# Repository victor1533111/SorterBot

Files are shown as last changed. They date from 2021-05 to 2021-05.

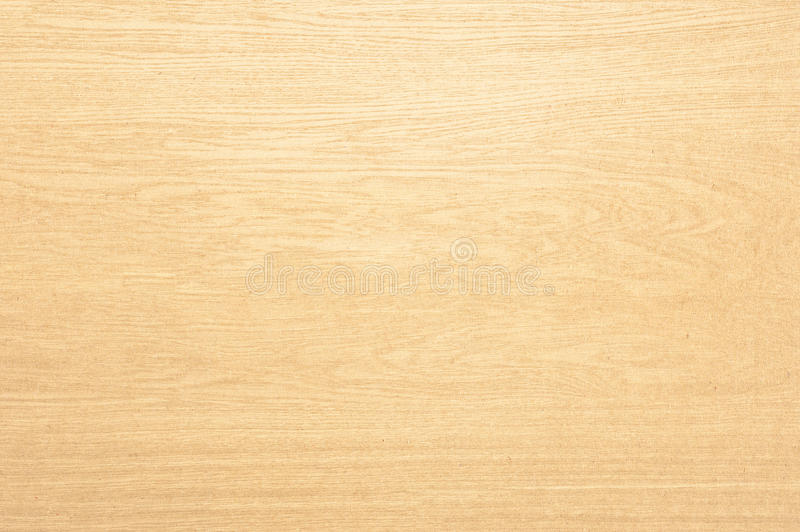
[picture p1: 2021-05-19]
COMPONENTES/TEXTURAS/Colores/textura-de-madera-de-color-claro-27235359.jpg

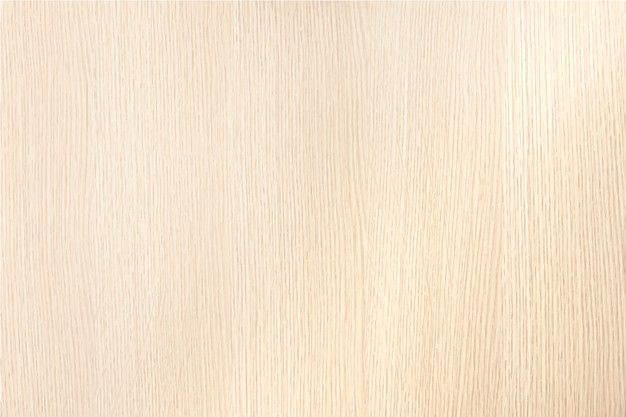
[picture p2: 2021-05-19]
COMPONENTES/TEXTURAS/Colores/wood-texture-background_28943-556.png

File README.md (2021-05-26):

# SorterBot 

<p align="Left">

 </p>

## Table of contents
* [Repository Introduction](#Repository-Introduction)
* [Video](#Video)
* [Code dependencies](#Code-dependencies )
  * [Instalation and uses](#Instalation-and-uses )
* [Project description](#Project-description)
* [Electronic components](#Electronic-components)
* [Hardware Scheme ](#Hardware-Scheme )
* [Extra components and 3D pieces](#Extra-components-and-3D-pieces )
* [Software Architecture ](#Software-Architecture )
* [Simulation Strategy and implementation ](#Simulation-Strategy-and-implementation )
* [Tests](#Tests)
  * [Title sorting test](#Title-sorting-test)
  * [Data sorting test](#Data-sorting-test)
  * [Sheet detection test](#Sheet-detection-test)
  * [Sheet Orientation test](#Sheet-Orientation-test)
* [Contributions](#Contributions)
* [Authors](#Authors )
* [References](#References)

## Repository Introduction
This repository contains all the software modules, all the 3d files and the scenarios that make up our robotics project.
The available code and the 3d designs have been designed by the members of the RPL 2020-2021 group of computer engineering of the UAB formed by Cristian Gutiérrez, Carlos Peña and Víctor Batista and directed by the tutors Luis Vilariano and Carlos García.

## Video

Video (https://www.youtube.com/watch?v=GDZ8xmWGUts)

## Code dependencies

-Tesseract OCR (pipenv , Pillow , pythonRLSA )

-OpenCV

-Jupyter

-CoppeliaSim

-Fuzzywuzzy

   * ## Instalation and uses
   The first thing to do is to install tesseract, to do this you have to access the code folder and run the tesseract application, once run just select the next option until the    last tab where you have to select finish. Important not to change the installation path since it will be the one used in the execution of the code.
   With respect to the rest of dependencies it is necessary to accede to the program and to change the second block of code of markdown to code and to execute it.
   Once the requirements have been installed, perform the following steps:
   1. Open the coppeliasim program with the scenario you wish to run. 
   
   2. Access the jupyter notebook and run all the blocks.
  
   3. A box with two buttons will appear, click the button depending on the scenario you have chosen.

## Project description
SorterBot is a pick and place robot that through the use of a hydraulic pump and a suction cup is able to perform two functionalities which are to classify subject notes by their title and to sort them by the relevant date that appears in those notes.
To perform the first functionality SorterBot implements computer vision by means of a camera that allows it to visualize the content of the notes. From the content it analyzes, it saves the information of the titles in order to classify them according to the subject to which they correspond. Also note that in case there are sheets that do not contain information on subjects or there are more subjects than available spaces, it classifies them in a separate set.
The second functionality, as we have already mentioned, allows us to organize the notes of a subject by dates. For this SorterBot uses computer vision that allows it to visualize the content of the notes from which it extracts the date that appears at the top of the sheet. Once the date is obtained, it uses the Hanoi algorithm with which it groups the sheets in different blocks depending on whether they correspond to an older or more current date in order to place them in an orderly fashion.
To highlight as contributions that It is a project that has a direct and wide application since it is automating a very frequent problem, the sorting of physical documents and their classification into different categories, thus allowing its use in any work or leisure environment and that Our robot differs from other pick & place robots[1] because it can apply different strategies and algorithms to classify and group documents. It should be noted that these strategies are based on the treatment of images of documents and on obtaining their information, thus allowing us to use it in any case where there is text, since it does not focus on the form but on the content.

## Electronic components
■ 1x Arduino

■ 1x Vacuum pump 

■ 1x Suction cup 

■ 1x Raspberry pi

■ 1x Raspberry pi camera 

■ 1x Power supply unit (8v) 

■ 3x Servomotor (1 x MG995 ->15kg, 2x MG90S -> 2,2kg) -> require de 4.8 a 7.3 v

■ 1x Infrared proximity sensor 

■ 1x Robot Skeleton

## Hardware Scheme 

<p align="center">
 
 </p>
 
## Extra components and 3D pieces
■ 2 Buttons

■ Body

■ Rotational arm

■ Proximity sensor holder

■ Prismatic arm

■ Flexible suction tube

■ Camera support

■ Suction tube storage and prismatic overlay (Vacuum zone)

■ Base arm support

■ 6 bars

■ Nuts and bolts

■ Servomotor Box

<p align="center">
 
 </p>

The main part of SorterBot is the body which apart from being an important part as far as the weight distribution of the structure is concerned, is the part where the vacuum pump and the robot's computers are kept, which in this case are the arduino and the raspberry pi.
In the body itself we find two buttons placed on its square base that allow us to select between the sorting algorithm (red button) and the organization (green button).
Next to this body we find a rotational arm connected by 4 bars that allows us to increase the mobilization of the body in the axis of the and, in addition to perform a 360 degree angle by means of the servomotor that is incorporated in the servomotor box located on top of the arm.
On top of this arm we find the piece that allows us to partially cover the prismatic arm as it moves along the z-axis, in addition to being the receiver of the flexible suction tube that is connected to the vacuum pump that goes from the base to the storage and generates the suction force of the suction cup [2]. It should be noted that this part allows us to create a vacuum zone.
Finally we find the camera support attached to the rotational arm and the proximity sensor support attached to the prismatic arm.
These two supports allow us in the first case to hold the camera of the raspberry pi perpendicular to the points, as well as to protect it and in the second case to place the sensor near the suction cup to calculate the distance to the object.

## Software Architecture
<p align="center">
 
 </p>
  
## Simulation Strategy and implementation

To simulate the project the first thing we do is to define the 3D design of the robot
using the TinkerCad application.
Once the design is done we export it in MTL format to be able to import it into the
Coppelia Sim platform keeping its colors.
In this platform we add the pertinent links that correspond to the servomotors of
our robot and we add a sensor to be able to visualize objects and another sensor to
detect the proximity[3] to these.
Once the robot is assembled we have defined several scenarios both for the
realization of the algorithms and for testing.
The first of them is a scenario in which we have defined a work table, a set of 6 file
cabinets that are at the following angles 45,90,-90,120,-120,150,-150,180, and a series
of sheets containing information of various subjects that are oriented at the zero
position of the robot.

<p align="Center">


 </p>

These angles have been chosen because of the size of the sheets, otherwise the binders would collide.
Also note that the angle -45 is reserved for the orientation of the leaves, otherwise it could be the case that there are two leaves in which the top one is well oriented and the bottom one is badly oriented and consequently an erroneous calculation would be made as shown in the following image:

<p align="Center">


 </p>
In this scenario the robot is responsible for performing the classification algorithm for which it takes each sheet independently by using the proximity sensor that allows us to stop the arm before colliding with the sheets,  and takes them to the orientation angle to see whether or not it is necessary to rotate them. Once the sheet is well oriented, the extraction of the text and identification of the title is carried out and then, by means of a strategy of percentage [4] of appearance and similarity of words, it is placed in a filing cabinet or other. If there is no subject associated with the sheet, an empty file cabinet will be found to place it, and if there are no file cabinets, it will be placed in the file cabinet located at 180 degrees.
Finally, add that the algorithm ends when it returns to the initial position and observes that there is no sheet of paper.

As a second scenario we have used the same as the previous one but in this case the sheets are already classified in their respective filing cabinets as shown in the following image:
<p align="Center">
 
 </p>
In this scenario we perform the sorting algorithm for which the robot goes to each file cabinet, in a set order, and sorts the sheets by helping the two nearby file cabinets to perform the same.

The algorithm of sorting data is divided into two phases:<br />
1. Read dates: Reads all dates from the stack, storing in an auxiliary angle.<br />
2. Stack Sort Algorithm: Proceeds to sort the sheets, using a maximum of two binders and leaving them in a third one, which corresponds to the binder where the stack to be sorted was.

We make the abstraction of viewing the file cabinets with all their sheets as a stack with elements:
<p align="Center">


 </p>

## Tests
To test the different algorithm modules of the Sorterbot, we have created 3 different scenarios and 4 different test.
 * ## Title sorting test
In this scenario we have a series of sheets with titles with different characteristics such as different sizes, numbers, strange symbols... In this case the scenario that we use is the second scenario and it is used to perform the title test in which the correct extraction of these titles will be checked with the corresponding elimination of elements that do not provide information. To evaluate the robustness of this title, the comparison of similarity with the correct titles is applied to make the sum of the percentages of similarity error.

It should be noted that the results obtained for this test have a 1.5 percent error rate.
 * ## Data sorting test  
 
The test itself consists of storing the result of the sorting in a list along the total sorting of all file cabinets.
Finally it is compared with the expected result to see if the sorting has been done correctly.
This test is useful to detect errors in the camera, the sorting algorithm and the general and functional operation of the MVP.
As a result, we have obtained the correct identification and conversion of all the dates

 * ## Sheet detection test
This test is performed in scenario 2 aswell.
The purpose of this test is to check that when there is an empty tray, the robot ignores this tray and continues with the sorting.
As results we have not obtained any problem in this test and its correct resolution has been performed.
 * ## Sheet Orientation test
In this case the test belongs to the third scenario which consist in only one filing cabinet in position -90 and a pile of misguided sheets as shown in the following image:
<p align="Center">

</p>
In this scenario we test the orientation algorithm for which the robot picks a sheet from the origin pile, then it moves it to orientation -45 where aren’t any noises, there the camera takes a photo of the sheet. Finaly we use computer vision techniques to take the longest line in the image corresponding to the sheet’s heigh, we detect angle of that line and then we proceed to correctly orientate it and place it in the filing cabinet.

The test consists in calculate the total error, the sum of the absolute error of all the sheets after being properly orientated.



As we can see, in a sample of 20 sheets the sum of existing errors was below 1 degree.

## Contributions
This is open source, any contribution is welcome. 

## Authors
Víctor Batista Medeiros - <a href="https://github.com/victor1533111">Github</a>

Carlos Peña de Pedro - <a href="https://github.com/CarlosPenaDePedro">Github</a>

Cristian Gutiérrez Gómez - <a href="https://github.com/cristiangutierrz">Github</a>

## References

[1] FANUC America Corporation (16 mar 2018). High Speed SCARA Robot for Pick & Place [YouTube]. https://youtu.be/-m1oKuFkSTE

[2] How to Control Vacuum Pump Air Pump Suction for Robotic Arm (January 30, 2021). [Web Page]. https://create.arduino.cc/projecthub/ronfrtek/how-to-control-vacuum-pump-air-pump-suction-for-robotic-arm-5de318

[3] Armesto, L. (12 feb 2020). Cómo Usar los Sensores de Proximidad para Permanecer entre Paredes [YouTube]. https://youtu.be/j4dMnAPZu70

[4] Gitau, C. (2020, 11 enero). Fuzzy String Matching - Towards Data Science. Medium. https://towardsdatascience.com/fuzzy-string-matching-in-python

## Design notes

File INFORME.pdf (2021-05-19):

RPL - Computer Engineering. UAB (Barcelona) 2020-2021

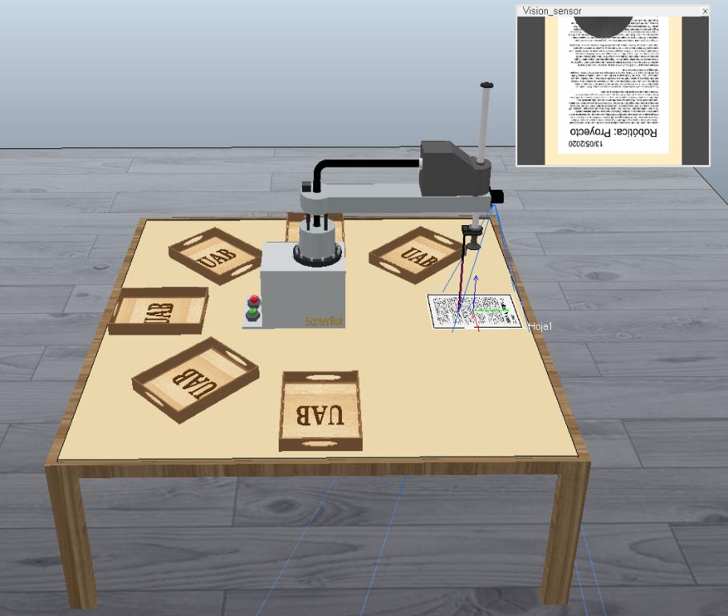
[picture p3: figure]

# SorterBot

Hydraulic arm that classifies notes according to the subject by computer vision and allows them to be sorted by date.

PROJECT SPRINT #4.
DATE: 18th May 2021
Víctor Batista Medeiros-1533111 Cristian Gutiérrez Gómez-1532397 Carlos Peña de Pedro-1532529

SorterBot

# Table of Contents

Project description | 1
Electronic components | 2
Schemes | 3
Amazing contributions , extra components and 3D pieces | 5
Description and use of pieces | 6
Simulation strategy | 8
Foreseen risks and contingency plan | 14

Sprint #3
Date:28 April 2021
SorterBot | 1

# SorterBot

Hydraulic arm that classifies notes according to the subject by computer vision and allows them to be sorted by date.

Project description

SorterBot is a pick and place robot that through the use of a hydraulic pump and a suction cup is able to perform two functionalities which are to classify subject notes by their title and to sort them by the relevant date that appears in those notes.

To perform the first functionality SorterBot implements computer vision by means of a camera that allows it to visualize the content of the notes. From the content it analyzes, it saves the information of the titles in order to classify them according to the subject to which they correspond. Also note that in case there are sheets that do not contain information on subjects or there are more subjects than available spaces, it classifies them in a separate set.

The second functionality, as we have already mentioned, allows us to organize the notes of a subject by dates. For this SorterBot uses computer vision that allows it to visualize the content of the notes from which it extracts the date that appears at the top of the sheet. Once the date is obtained, it uses the Hanoi algorithm with which it groups the sheets in different blocks depending on whether they correspond to an older or more current date in order to place them in an orderly fashion.

SorterBot | 2

Electronic components

■ | 1x Arduino
■ | 1x Vacuum pump
■ | 1x Suction cup
■ | 1x Raspberry pi
■ | 1x Raspberry pi camera
■ | 1x Power supply unit (8v)
■ | 3x Servomotor (1 x MG995 ->15kg, 2x MG90S -> 2,2kg) -> require de 4.8 a 7.3 v

■ 1x Infrared proximity sensor

■ 1x Robot Skeleton

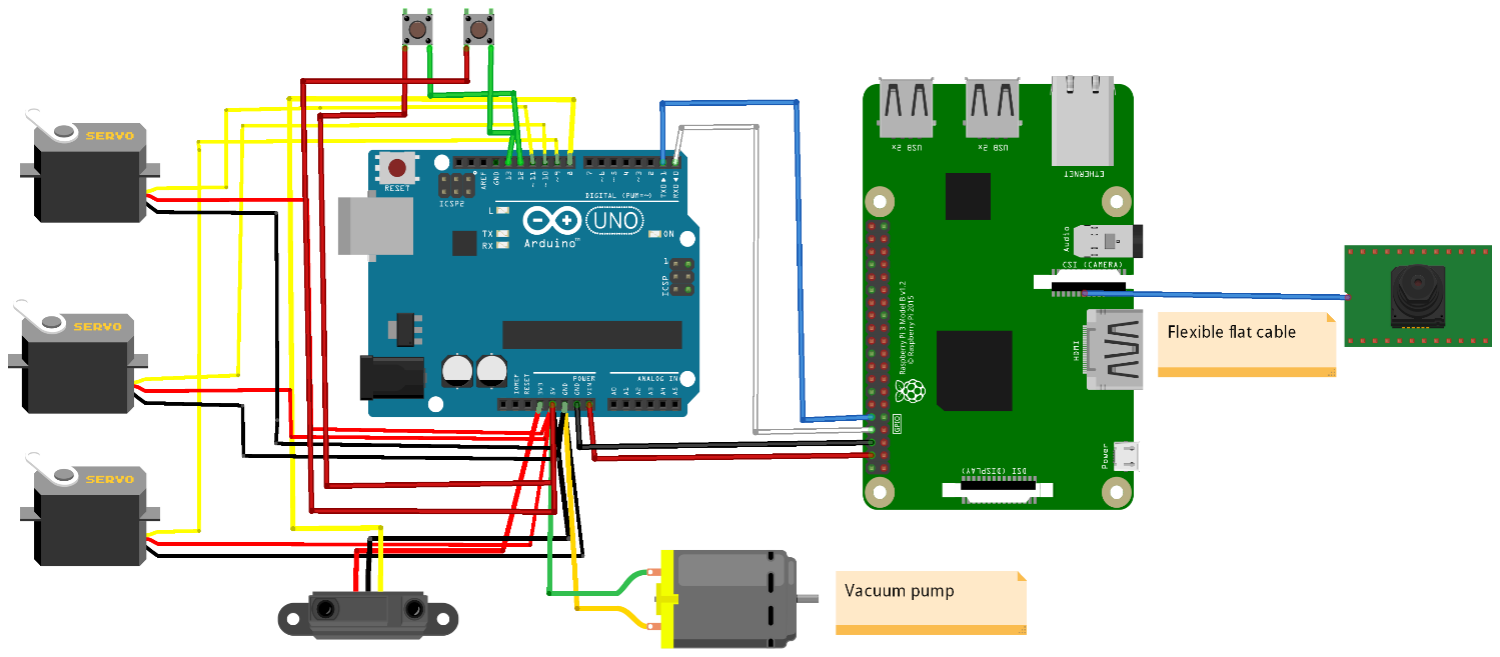
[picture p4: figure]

SorterBot | 3

Hardware Scheme

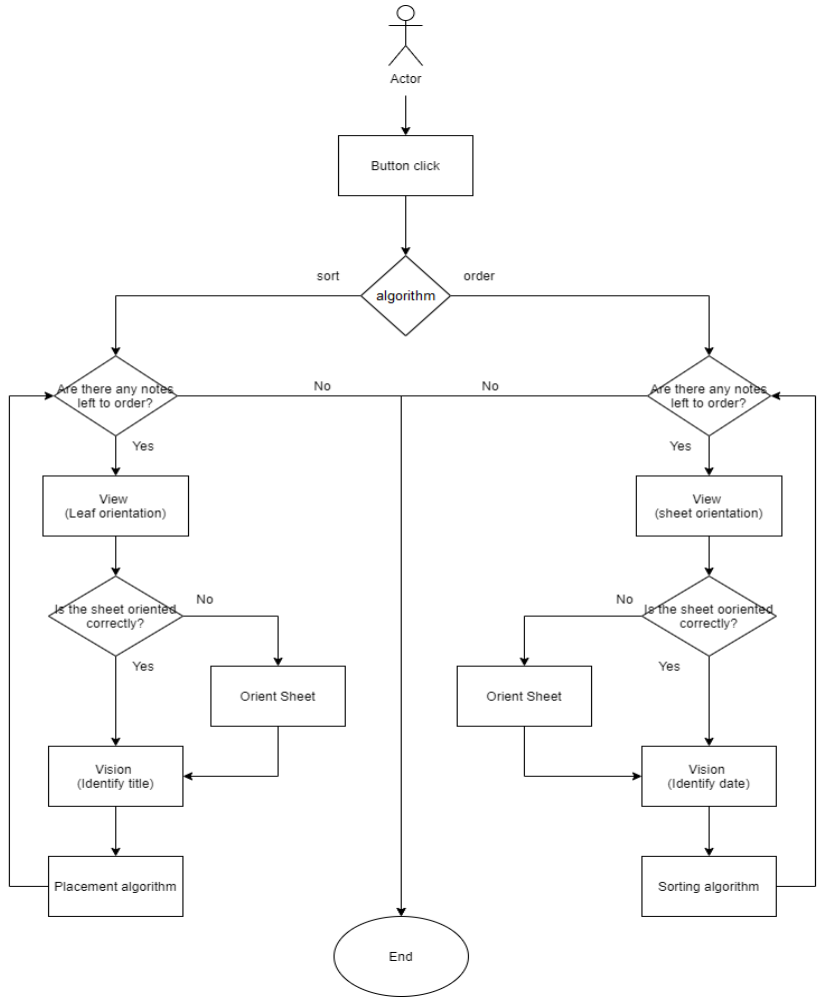
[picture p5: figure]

SorterBot | 4

Software Architecture

SorterBot | 5

Amazing contributions

■ It is a project that has a direct and wide application since it is automating a very frequent problem, the sorting of physical documents and their classification into different categories, thus allowing its use in any work or leisure environment.

■ Our robot differs from other pick & place robots[1] because it can apply different strategies and algorithms to classify and group documents. It should be noted that these strategies are based on the treatment of images of documents and on obtaining their information, thus allowing us to use it in any case where there is text, since it does not focus on the form but on the content.

Extra components and 3D pieces

■ 2 Buttons

■ Body

■ Rotational arm

■ Proximity sensor holder

■ Prismatic arm

■ Flexible suction tube

■ Camera support

■ Suction tube storage and prismatic overlay (Vacuum zone)

■ Base arm support

■ 6 bars

■ Nuts and bolts

■ Servomotor Box

SorterBot | 6

Description and use of pieces

The main part of SorterBot is the body which apart from being an important part as far as the weight distribution of the structure is concerned, is the part where the vacuum pump and the robot's computers are kept, which in this case are the arduino and the raspberry pi.

In the body itself we find two buttons placed on its square base that allow us to select between the sorting algorithm (red button) and the organization (green button).

Next to this body we find a rotational arm connected by 4 bars that allows us to increase the mobilization of the body in the axis of the and, in addition to perform a 360 degree angle by means of the servomotor that is incorporated in the servomotor box located on top of the arm.

On top of this arm we find the piece that allows us to partially cover the prismatic arm as it moves along the z-axis, in addition to being the receiver of the flexible suction tube that is connected to the vacuum pump that goes from the base to the storage and generates the suction force of the suction cup [2]. It should be noted that this part allows us to create a vacuum zone.

Finally we find the camera support attached to the rotational arm and the proximity sensor support attached to the prismatic arm.

These two supports allow us in the first case to hold the camera of the raspberry pi perpendicular to the points, as well as to protect it and in the second case to place the sensor near the suction cup to calculate the distance to the object.

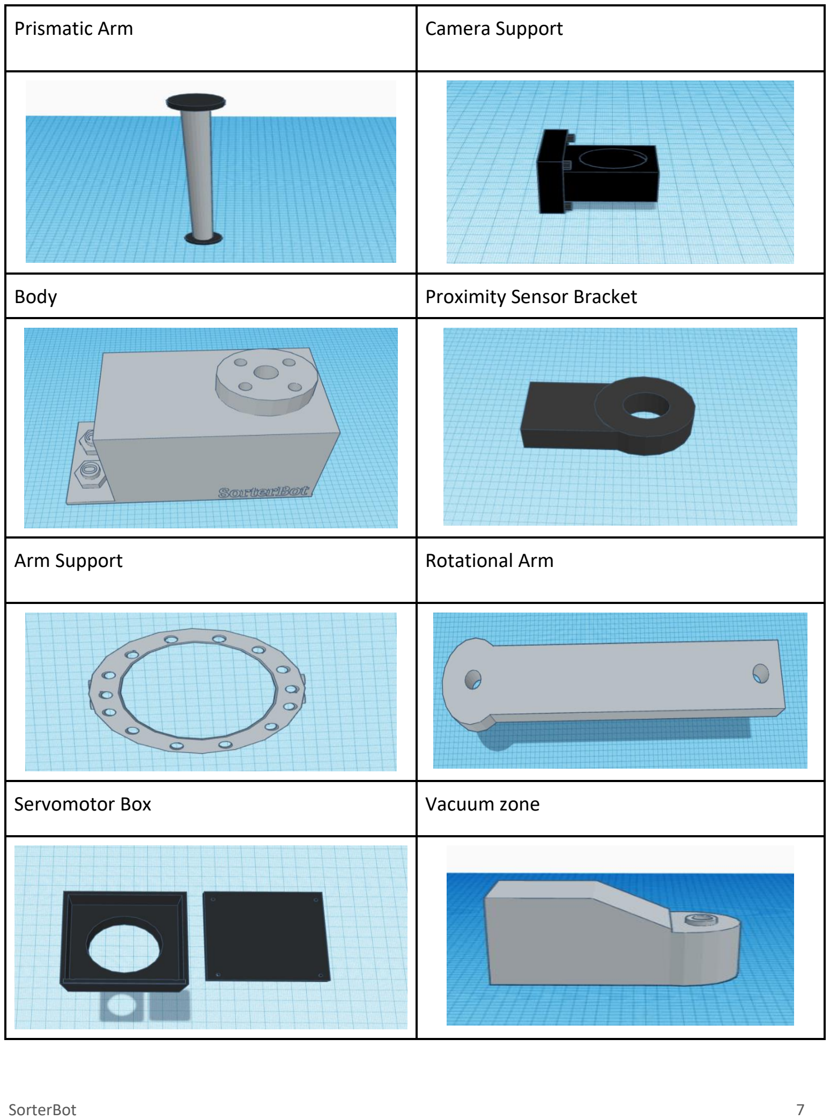
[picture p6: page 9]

SorterBot | 7
Prismatic Arm | Camera Support
Body | Proximity Sensor Bracket
Arm Support | Rotational Arm
Servomotor Box | Vacuum zone

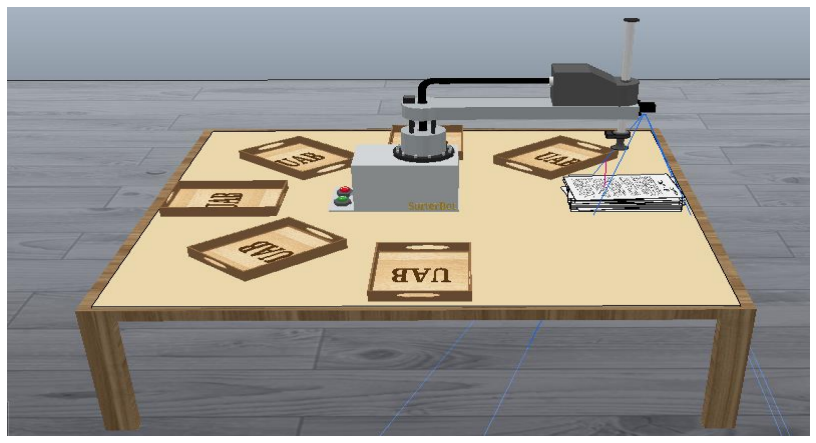
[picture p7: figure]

SorterBot | 8

Simulation Strategy

To simulate the project the first thing we do is to define the 3D design of the robot using the TinkerCad application.
Once the design is done we export it in MTL format to be able to import it into the Coppelia Sim platform keeping its colors.
In this platform we add the pertinent links that correspond to the servomotors of our robot and we add a sensor to be able to visualize objects and another sensor to detect the proximity[3] to these.
Once the robot is assembled we have defined several scenarios both for the realization of the algorithms and for testing.
The first of them is a scenario in which we have defined a work table, a set of 6 file cabinets that are at the following angles 45,90,-90,120,-120,150,-150,180, and a series of sheets containing information of various subjects that are oriented at the zero position of the robot

Image 1: Clasification scenario.

These angles have been chosen because of the size of the sheets, otherwise the binders would collide.

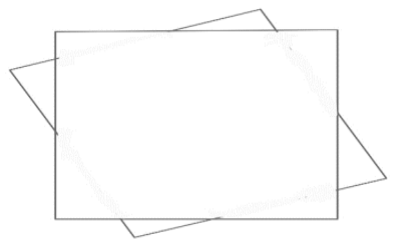
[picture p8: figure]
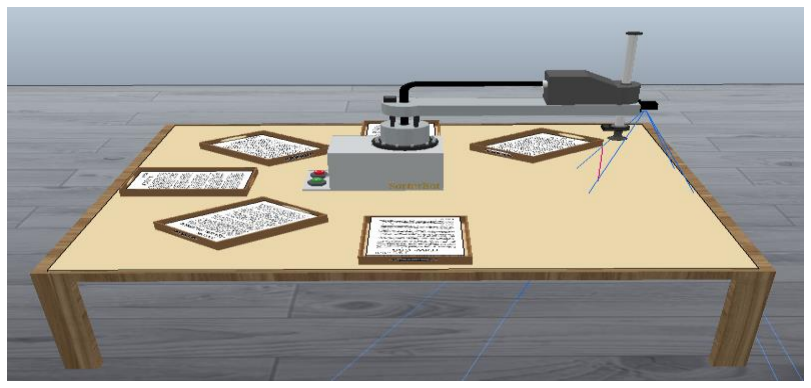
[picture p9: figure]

SorterBot | 9

Also note that the angle -45 is reserved for the orientation of the leaves, otherwise it could be the case that there are two leaves in which the top one is well oriented and the bottom one is badly oriented and consequently an erroneous calculation would be made as shown in the following image:

Image 2: Set of leaves with the lower leaf oriented wrongly.

In this scenario the robot is responsible for performing the classification algorithm for which it takes each sheet independently by using the proximity sensor that allows us to stop the arm before colliding with the sheets, and takes them to the orientation angle to see whether or not it is necessary to rotate them. Once the sheet is well oriented, the extraction of the text and identification of the title is carried out and then, by means of a strategy of percentage [4] of appearance and similarity of words, it is placed in a filing cabinet or other. If there is no subject associated with the sheet, an empty file cabinet will be found to place it, and if there are no file cabinets, it will be placed in the file cabinet located at 180 degrees.

As a second scenario we have used the same as the previous one but in this case the
sheets are already classified in their respective filing cabinets as shown in the following image:

Image 3: Management scenario.

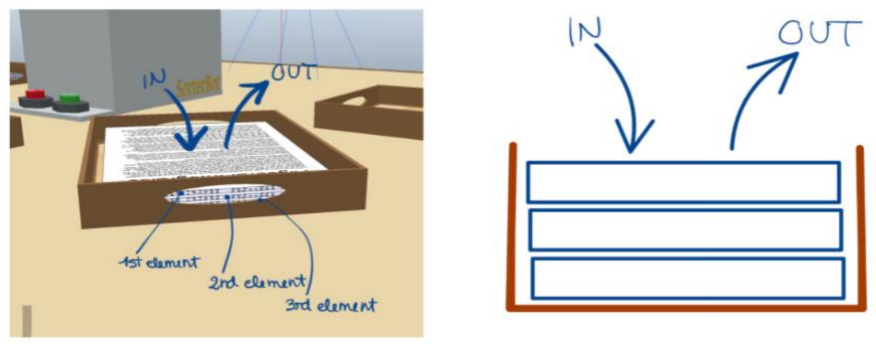
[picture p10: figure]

SorterBot | 10

In this scenario we perform the sorting algorithm for which the robot goes to each file cabinet, in a set order, and sorts the sheets by helping the two nearby file cabinets to perform the same.

It is divided into two phases:

1. Read dates: Reads all dates from the stack, storing in an auxiliary angle.
2. Stack Sort Algorithm: Proceeds to sort the sheets, using a maximum of two binders and leaving them in a third one, which corresponds to the binder where the stack to be sorted was.

We make the abstraction of viewing the file cabinets with all their sheets as a stack with elements:

Image 4: The stack abstraction.

Pseudocode Stack Sort Algorithm

:param unsorted_date_list:
:param a1: angle where the stack is located after reading the dates :param a2: angle at which we will leave the stack sorted
:param atemp: an angle to be used to assist in sorting (will remain empty) returns :param sorted_date_list:

WHILE unsorted_date_list HAS ELEMENTS:
Grab the first paper sheet on the stack (FirstSheet) WHILE sorted_date_list HAS ELEMENTS:
IF date(ordered_date_list[-1]) > date (FirstSheet):
Leave the current sheet to the the axillary “atemp” stack Grab the first paper sheet on the “a2” stack
Leave the current sheet to the the “a1” stack

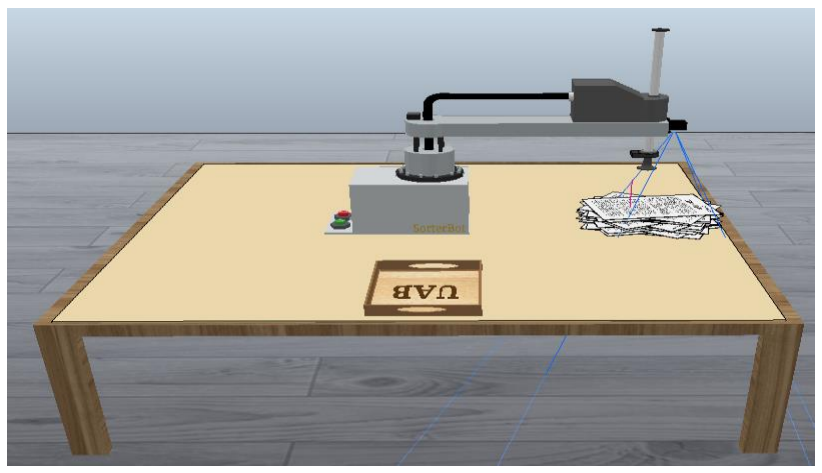
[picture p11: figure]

SorterBot | 11

ELSE:
BREAK
IF sorted_date_list HAS NO ELEMENTS:
Leave the current sheet at the original stack angle “a2” ELSE:
Grab the sheet for the axillary “atemp” stack

Also, in this scenario we perform two tests:

- test_resultat_correcte
It consists of storing the result of the sorting in a list along the total sorting of all file cabinets.
Finally it is compared with the expected result to see if the sorting has been done correctly.
This test is useful to detect errors in the camera, the sorting algorithm and the general and functional operation of the MVP.
- test_arxivador_buit
The purpose of this test is to check that when there is an empty tray, the robot ignores this tray and continues with the sorting.

The fourth scenario consist in only one filing cabinet in position -90 and a pile of misguided sheets as shown in the following image:

Image 5: Management scenario.

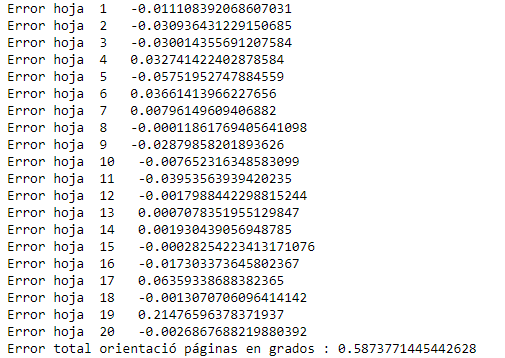
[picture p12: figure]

SorterBot | 12

In this scenario we test the orientation algorithm for which the robot picks a sheet from the origin pile, then it moves it to orientation -45 where aren’t any noises and the camera takes a photo of the sheet. Then we use computer vision techniques to take the longest line in the image corresponding to the sheet’s heigh, we detect angle of that line and then we proceed to correctly orientate it and place it in the filing cabinet.

The test consists in calculate the total error, the sum of the absolute error of all the sheets after being properly orientated.

As we can see in a sample of 20 sheets the sum of existing errors was below 1 degree.

Finally, as the last scenario, we find a scenario in which we have a series of sheets with titles with different characteristics such as different sizes, numbers, strange symbols... In this case this scenario is used to perform the title test in which the correct extraction of these titles will be checked with the corresponding elimination of elements that do not provide information. To evaluate the robustness of this title, the comparison of similarity with the correct titles is applied to make the sum of the percentages of similarity error.

It should be noted that the results obtained for this test have a 1.5 percent error rate.

SorterBot | 13

Foreseen risks and contingency plan

Risk # | Description | Probability (High/Medium/L ow) | Impact (High/Medium/L ow) | Contingency plan
1 | Excessive suction force. | High | High | Correctly adjust the suction valve output.
2 | Inadequate height when depositing foils. | High | High | Use of the motion sensor to correctly adjust the displacement of the prismatic axis
3 | Failures in the title detection system.. | Low | High | Extensive screening and classification of folios by title
4 | Obstruction of the robot by an object not foreseen in the working area. | Low | High | Periodic review of the work area.
5 | Failure to raise the prismatic axis causing the robot to hit the sheets. | Low | High | Automatically raise the prismatic axis to a height greater than the maximum thickness of the piles of foils.

SorterBot | 14
Risk # | Description | Probability (High/Medium/L ow) | Impact (High/Medium/L ow) | Contingency plan
6 | Exceeding the maximum number of subjects to be graded. | Low | Low | Move the excess subject sheets to the default pile.
7 | Folios without content or title to classify. | Low | Low | Move the sheets to the default pile.
8 | Sheets with different date formats. | Medium | Medium | After reading the dates transform them all to the same format.
9 | Undated sheets. | Medium | Low | If a sheet has no date, when using the sort function it will be deposited in a pile in the opposite place to the original one.
10 | Overlapping orientations | High | High | When two sheets are stacked, if the first one is straight and the bottom one is twisted, it will detect the orientation of the second one, so it will be necessary to move each sheet to an empty area before correcting its orientation

SorterBot | 15

References

[1] FANUC America Corporation (16 mar 2018). High Speed SCARA Robot for Pick & Place [YouTube]. https://youtu.be/-m1oKuFkSTE
[2] How to Control Vacuum Pump Air Pump Suction for Robotic Arm (January 30, 2021). [Web Page]. https://create.arduino.cc/projecthub/ronfrtek/how-to-control-vacuum-pump-air-pump-suction-for-robotic-arm-5de318 (https://create.arduino.cc/projecthub/ronfrtek/how-to-control-vacuum-pump-air-pump-suction-for-robotic-arm-5de318)
[3] Armesto, L. (12 feb 2020). Cómo Usar los Sensores de Proximidad para Permanecer entre Paredes [YouTube]. https://youtu.be/j4dMnAPZu70
[4] Gitau, C. (2020, 11 enero). Fuzzy String Matching - Towards Data Science. Medium. https://towardsdatascience.com/fuzzy-string-matching-in-python

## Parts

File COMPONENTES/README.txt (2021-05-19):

En MTL encontraras todos los componentes necesarios para realizar el robot simulable
Mientras que en STL encontraras solo las piezas que se requieren imprimir con una impresora 3D.

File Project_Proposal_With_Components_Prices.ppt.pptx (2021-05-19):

## SORTERBOT

Brazo hidráulico que clasifica apuntes en función de la asignatura mediante visión por computador y que permite ordenarlos por fecha.

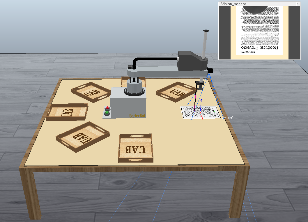
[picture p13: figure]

GROUP_07
Victor Batista Medeiros -1533111
Cristian Gutiérrez Gómez - 1532397
Carlos Peña de Pedro -1532529

Robòtica, llenguatge I planificació – Enginyeria informàtica - uab

## SORTERBOT

Component | Units | Price/unit | Budget
KIT succión (Arduino, bomba vacio, gripper, cables y tubos) | 1 | 33,58 | 33,58
Raspberry pi | 1 | 19,95 | 19,95
RaspBerry pi Camera | 1 | 15,17 | 15,17
Fuente Alimentacion (12v) | 1 | 15,99 | 15,99
Servomotor ( 1 x MG995 ->15kg) | 1 | 6,96 | 6.96
Servomotor (2x MG90S -> 2,2kg) | 2 | 4,95 | 9,9
Sensor infrarrojo de proximidad | 1 | 6.18 | 6.18
Esqueleto Robot | 1 | - | -
TOTAL: | | | 107,73

## Altres enllaços

Projecte en el qual està inspirat

https://youtu.be/eVz7mOJVvQc
https://youtu.be/Tm_Iw5IqTVs

- https://create.arduino.cc/projecthub/ronfrtek/how-to-control-vacuum-pump-air-pump-suction-for-robotic-arm-5de318
- https://youtu.be/efHYZ-Fcfmw
- https://www.youtube.com/watch?v=Gmdvx8TKWOQ&ab_channel=kelongye
- https://es.wikipedia.org/wiki/Torres_de_Han%C3%B3i

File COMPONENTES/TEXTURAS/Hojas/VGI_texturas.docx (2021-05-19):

15/02/2021

VGI : Gabbor

Lorem ipsum dolor sit amet, consectetur adipiscing elit, sed do eiusmod tempor incididunt ut labore et dolore magna aliqua. Aliquet nibh praesent tristique magna sit amet. A diam maecenas sed enim. Orci phasellus egestas tellus rutrum. Porttitor lacus luctus accumsan tortor posuere ac ut consequat. Habitant morbi tristique senectus et. Dui faucibus in ornare quam viverra orci sagittis eu volutpat. Vestibulum sed arcu non odio euismod lacinia. Parturient montes nascetur ridiculus mus mauris. Arcu risus quis varius quam quisque. Elit scelerisque mauris pellentesque pulvinar pellentesque habitant morbi tristique. Sed turpis tincidunt id aliquet risus feugiat in ante metus. Pharetra convallis posuere morbi leo. Mattis nunc sed blandit libero. At augue eget arcu dictum varius duis. Quis auctor elit sed vulputate mi sit amet. Facilisis magna etiam tempor orci eu lobortis elementum nibh tellus. Morbi tristique senectus et netus et. Ornare arcu odio ut sem nulla pharetra diam sit. Pretium quam vulputate dignissim suspendisse in est ante.

Purus ut faucibus pulvinar elementum integer enim neque volutpat. In fermentum et sollicitudin ac orci. Odio tempor orci dapibus ultrices in iaculis nunc sed augue. Vitae suscipit tellus mauris a diam maecenas sed. Leo urna molestie at elementum eu facilisis sed odio. Convallis posuere morbi leo urna molestie at elementum eu. Interdum posuere lorem ipsum dolor sit amet. Turpis egestas sed tempus urna et pharetra pharetra. Mattis aliquam faucibus purus in massa. Faucibus scelerisque eleifend donec pretium. Id aliquet risus feugiat in ante metus dictum at.

Velit sed ullamcorper morbi tincidunt ornare massa. Iaculis eu non diam phasellus vestibulum lorem sed risus. Sit amet dictum sit amet justo donec enim diam. Sagittis nisl rhoncus mattis rhoncus urna neque viverra. Turpis egestas sed tempus urna. Feugiat scelerisque varius morbi enim. Vel turpis nunc eget lorem dolor sed. Aenean vel elit scelerisque mauris pellentesque. Mauris nunc congue nisi vitae. Volutpat consequat mauris nunc congue nisi. Id velit ut tortor pretium viverra suspendisse potenti nullam. Justo eget magna fermentum iaculis eu non diam phasellus. At varius vel pharetra vel turpis nunc eget lorem dolor. Mauris rhoncus aenean vel elit. Potenti nullam ac tortor vitae purus.

Et magnis dis parturient montes nascetur ridiculus. Eget gravida cum sociis natoque penatibus et. Porttitor massa id neque aliquam vestibulum morbi blandit. Aliquet porttitor lacus luctus accumsan. Euismod in pellentesque massa placerat duis ultricies lacus. Dui ut ornare lectus sit amet est. A iaculis at erat pellentesque adipiscing commodo. Molestie ac feugiat sed lectus vestibulum mattis ullamcorper velit. Amet nulla facilisi morbi tempus iaculis. Erat pellentesque adipiscing commodo elit at imperdiet dui accumsan sit. Proin fermentum leo vel orci porta non pulvinar. Sed faucibus turpis in eu mi. Praesent semper feugiat nibh sed pulvinar proin gravida hendrerit.

Nunc sed augue lacus viverra vitae congue. Platea dictumst quisque sagittis purus sit amet volutpat consequat mauris. Sed velit dignissim sodales ut eu sem integer vitae justo. Mi in nulla posuere sollicitudin aliquam ultrices sagittis orci. Est lorem ipsum dolor sit. Dolor sed viverra ipsum nunc aliquet bibendum enim. Vulputate sapien nec sagittis aliquam malesuada bibendum. Amet mauris commodo quis imperdiet massa tincidunt nunc pulvinar. Mi quis hendrerit dolor magna. Ultrices tincidunt arcu non sodales neque sodales ut etiam sit. Sed risus pretium quam vulputate dignissim suspendisse in. Interdum posuere lorem ipsum dolor sit amet. Morbi tristique senectus et netus et malesuada fames ac turpis. Sagittis nisl rhoncus mattis rhoncus urna. Lorem ipsum dolor sit amet

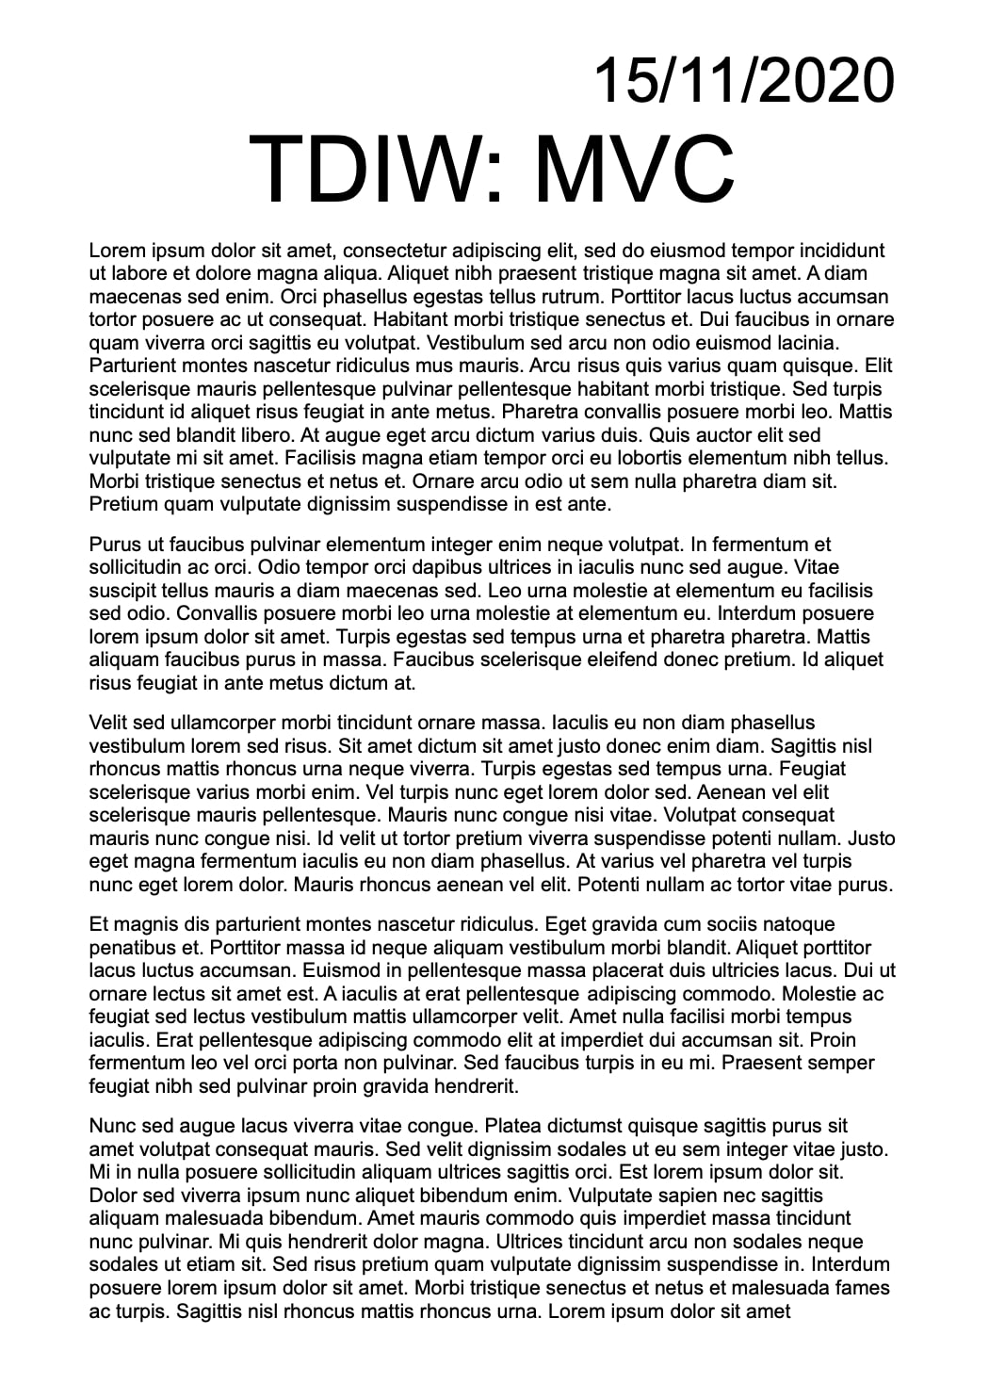
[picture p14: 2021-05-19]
COMPONENTES/TEXTURAS/Hojas/TDIW_MVC.jpg

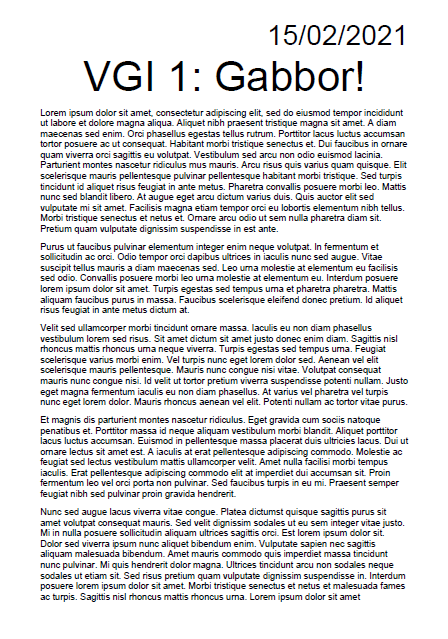
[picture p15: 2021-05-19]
COMPONENTES/TEXTURAS/Hojas/vgiii.PNG

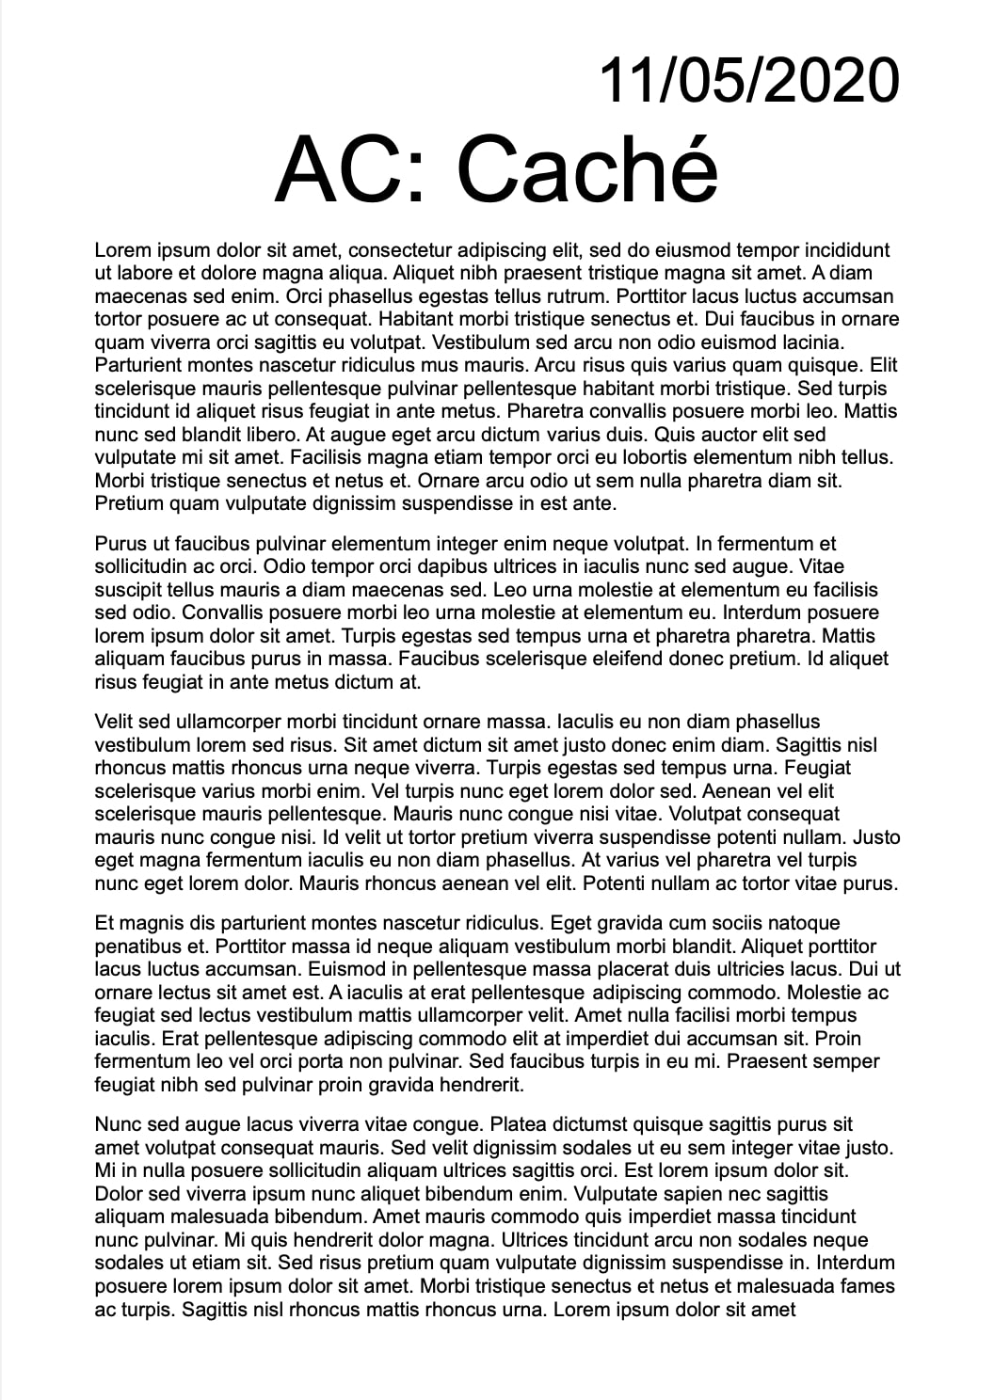
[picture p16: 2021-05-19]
COMPONENTES/TEXTURAS/Hojas/AC_Cache.jpg

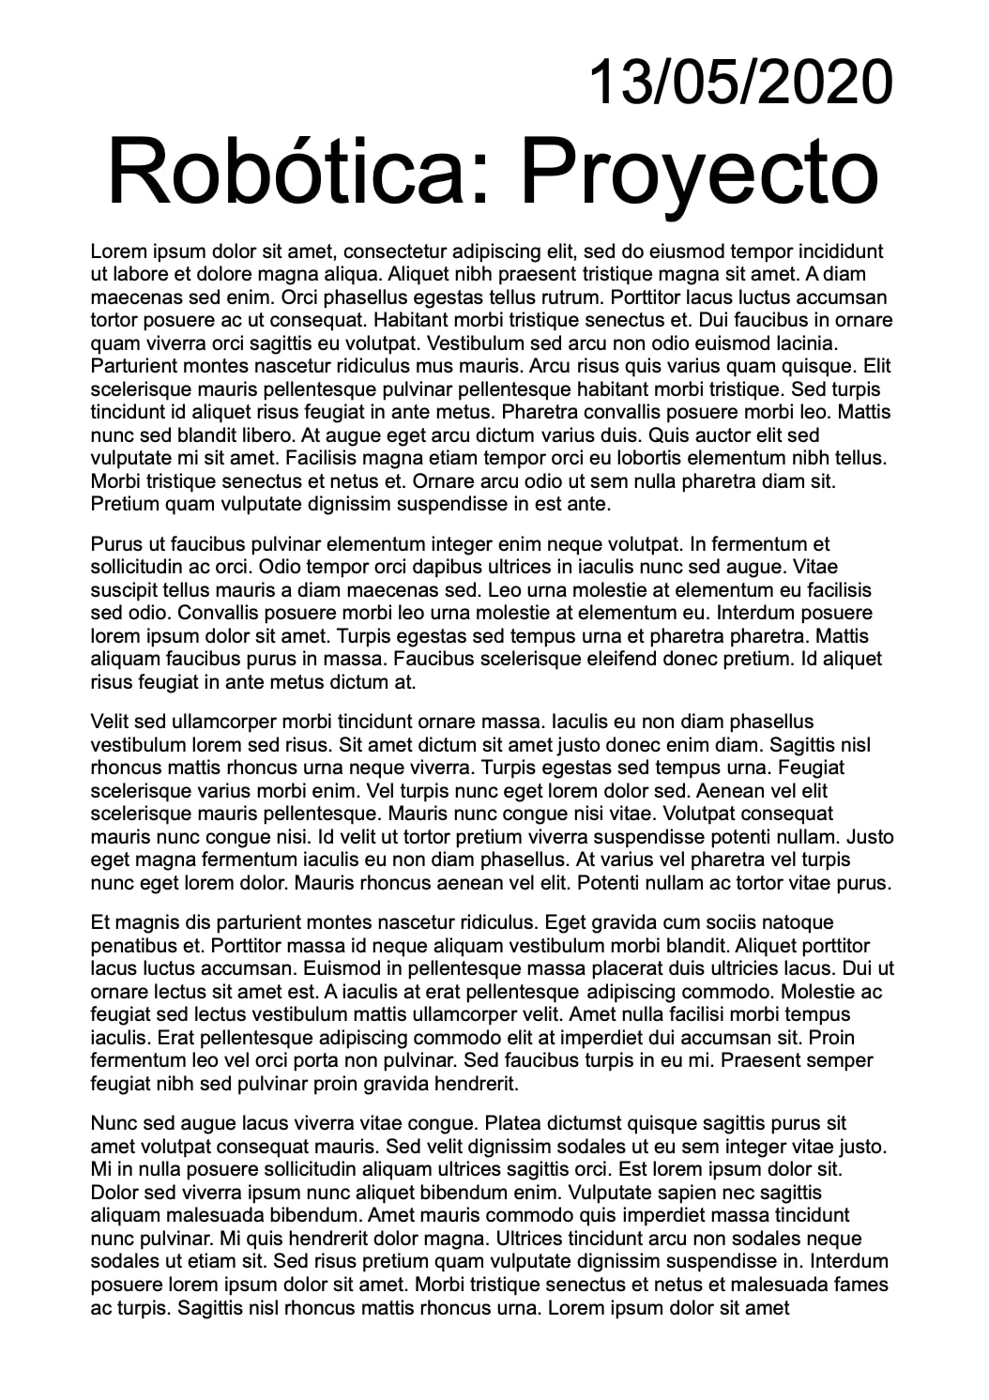
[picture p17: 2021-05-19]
COMPONENTES/TEXTURAS/Hojas/Robotica_Proyecto.jpg

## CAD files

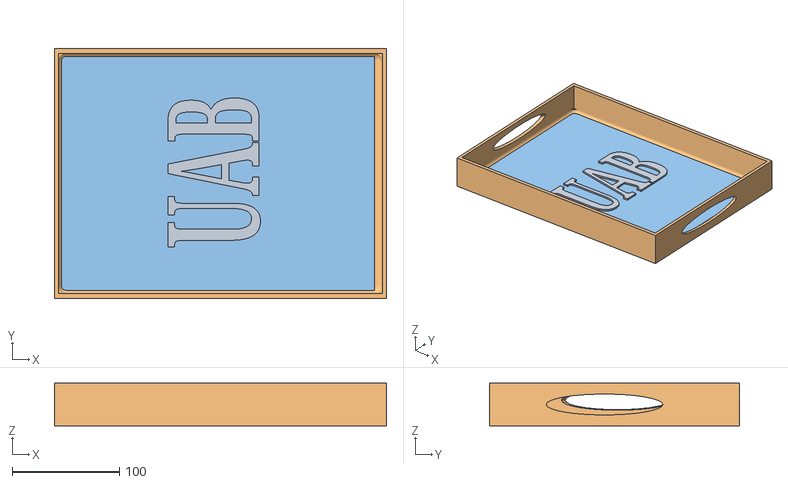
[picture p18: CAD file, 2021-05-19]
COMPONENTES/MTL/Archivador.obj
310.0 x 233.0 x 40.0

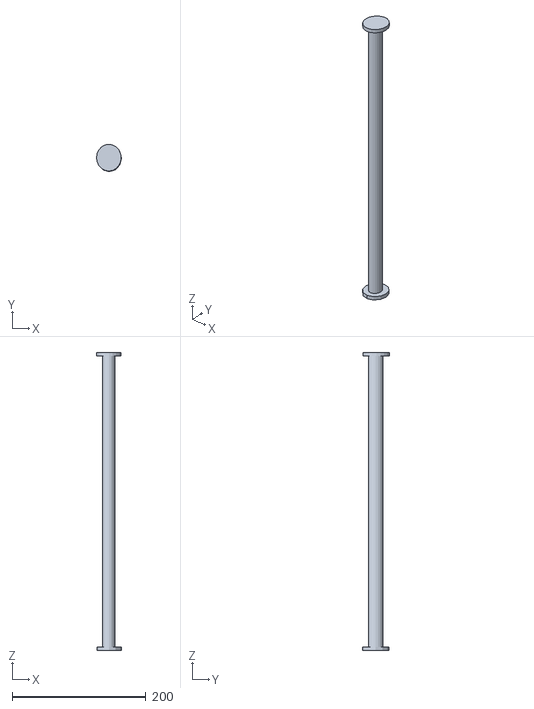
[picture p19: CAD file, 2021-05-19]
COMPONENTES/STL/Brazo_Prismatico.stl
37.5 x 41.0 x 446.0

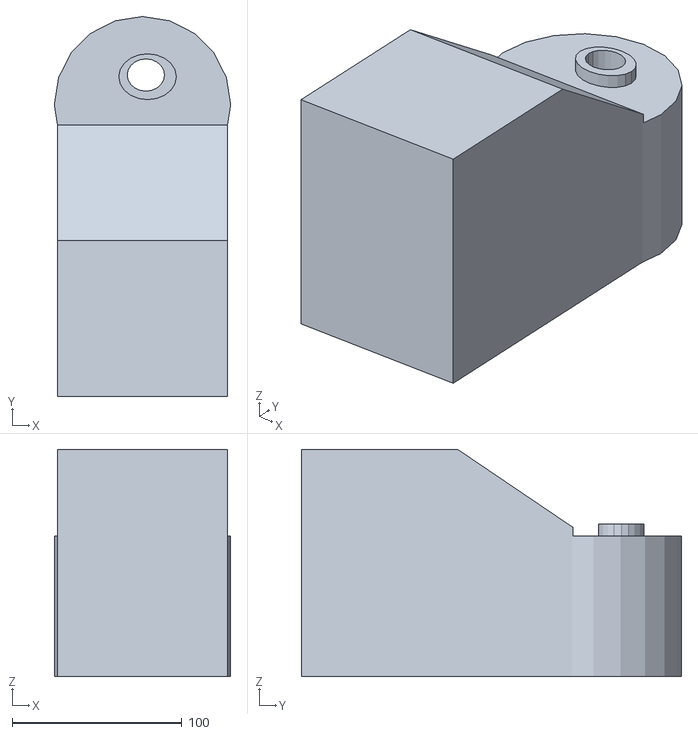
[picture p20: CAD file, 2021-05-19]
COMPONENTES/MTL/zonavacio.obj
104.0 x 224.0 x 134.0

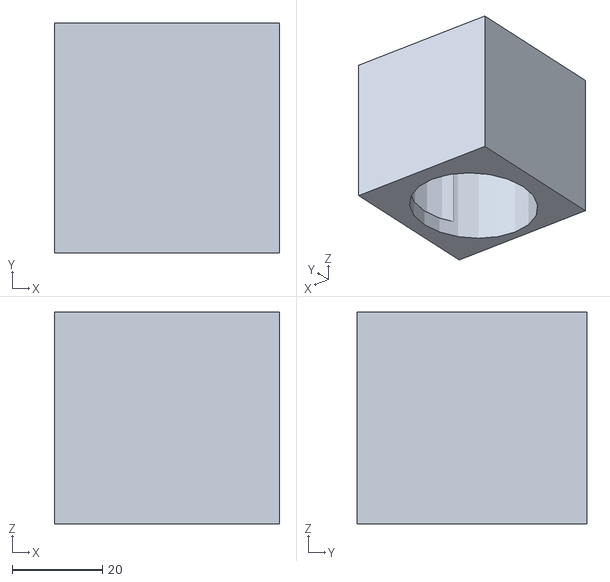
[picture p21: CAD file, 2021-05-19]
COMPONENTES/MTL/Soporte_camera.obj
50.0 x 51.0 x 47.0

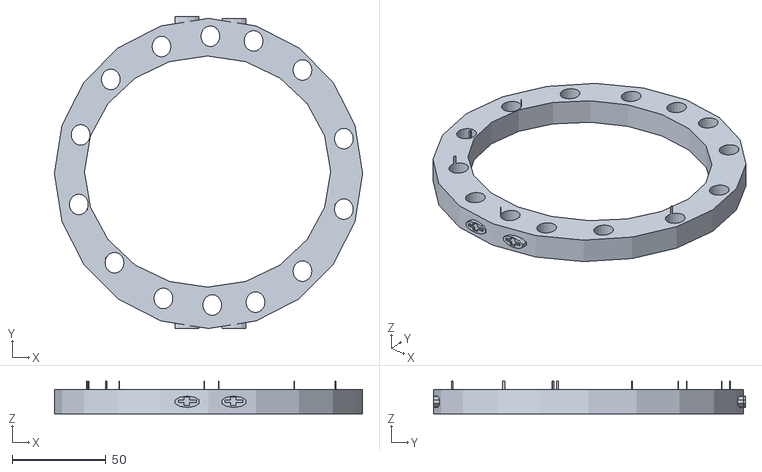
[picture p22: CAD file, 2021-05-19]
COMPONENTES/STL/Soporte_Brazo.stl
164.0 x 166.0 x 17.6

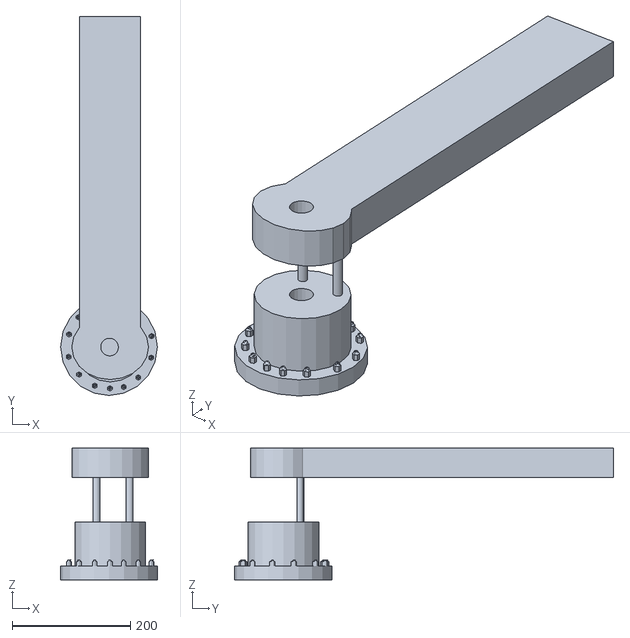
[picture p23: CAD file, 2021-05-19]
COMPONENTES/STL/Brazo rotacional.stl
164.0 x 642.0 x 223.0

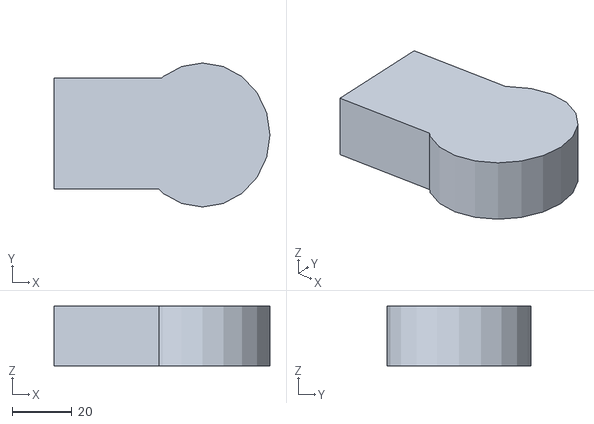
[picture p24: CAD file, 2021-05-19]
COMPONENTES/MTL/soporte_sensor.obj
72.0 x 48.0 x 20.0

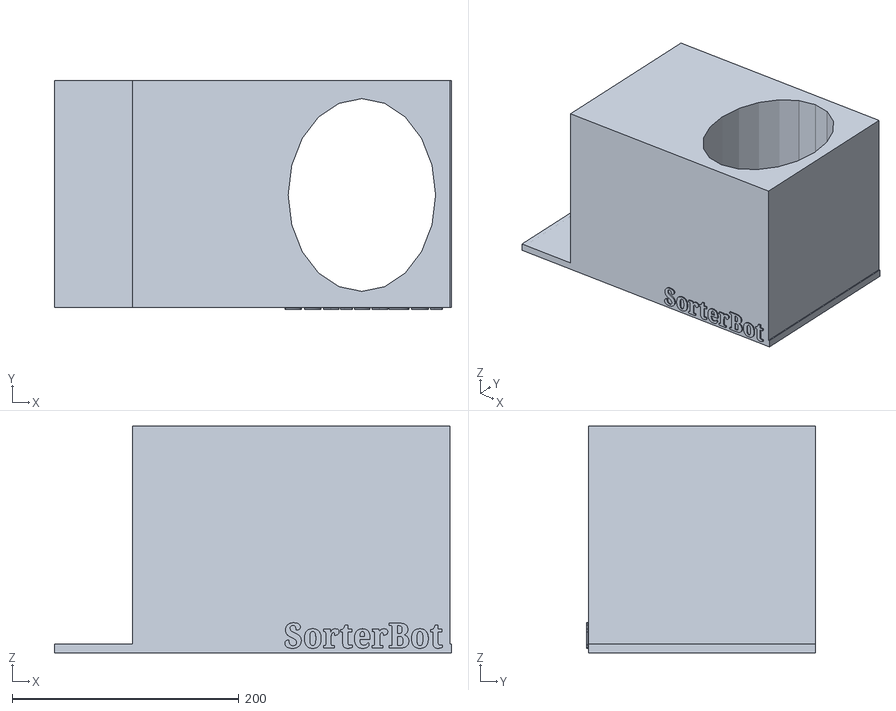
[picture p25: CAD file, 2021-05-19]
COMPONENTES/STL/Base.stl
350.0 x 202.0 x 200.0

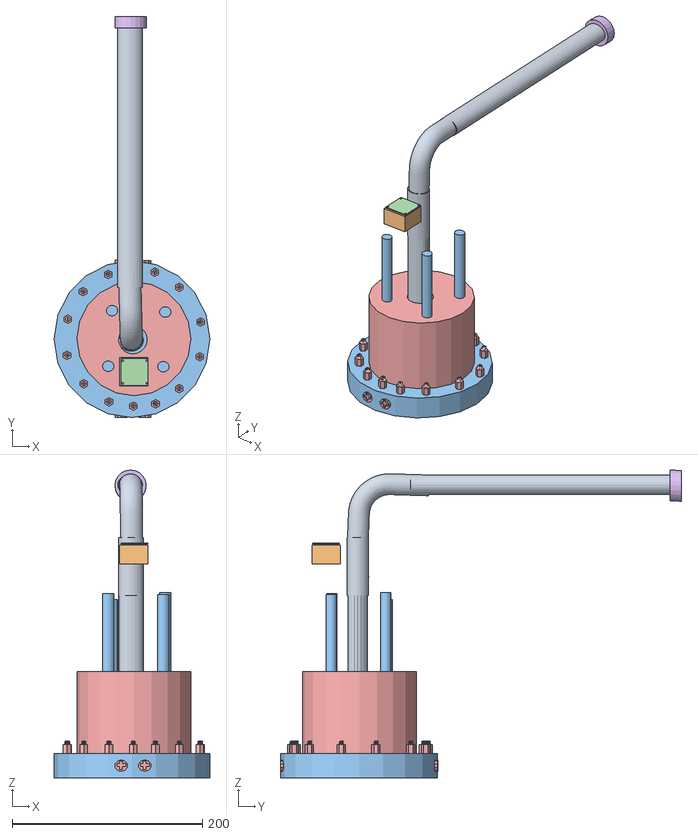
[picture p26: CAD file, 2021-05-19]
COMPONENTES/MTL/base.obj
164.0 x 422.0 x 324.0

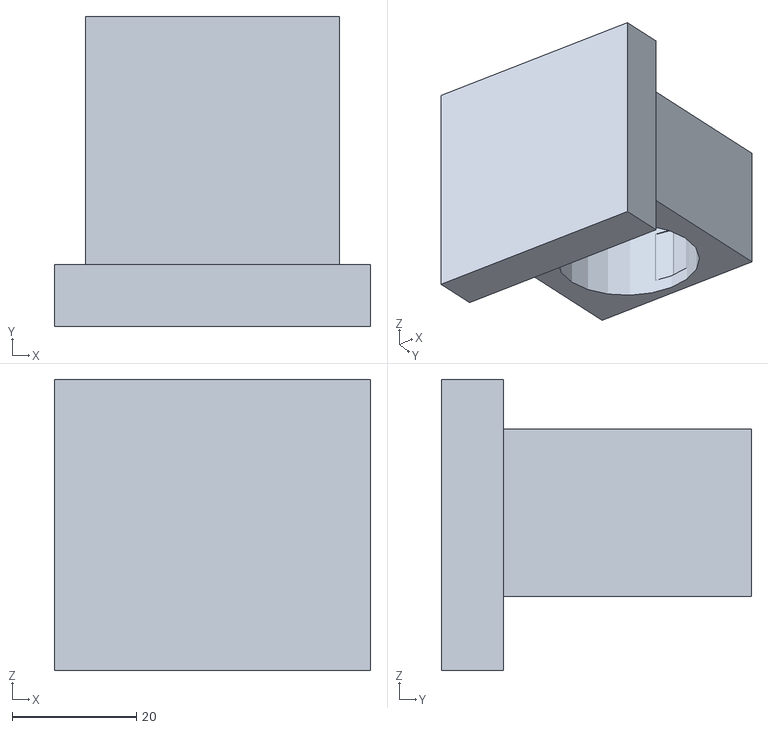
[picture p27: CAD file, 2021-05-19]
COMPONENTES/STL/Soporte_Camara.stl
51.0 x 50.0 x 47.0

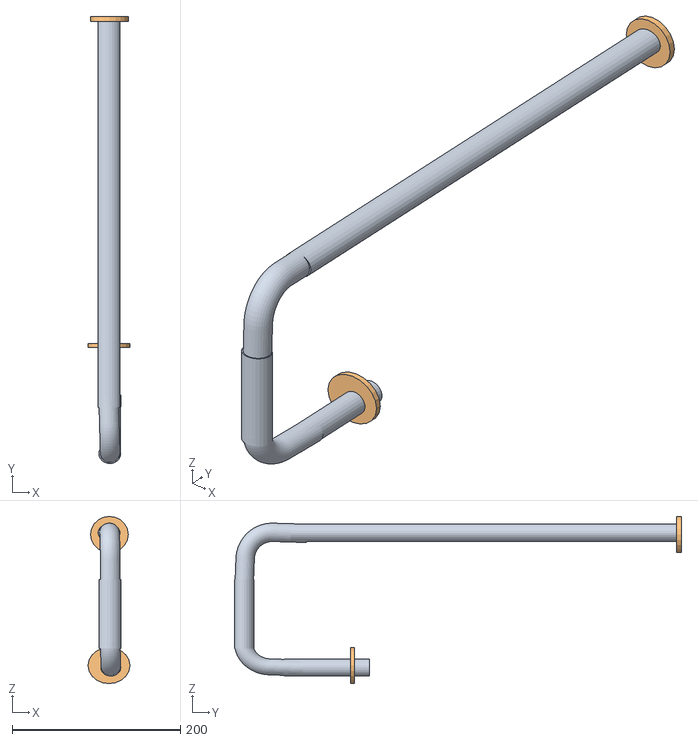
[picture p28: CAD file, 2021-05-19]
COMPONENTES/MTL/Tubo.obj
50.0 x 532.0 x 199.0

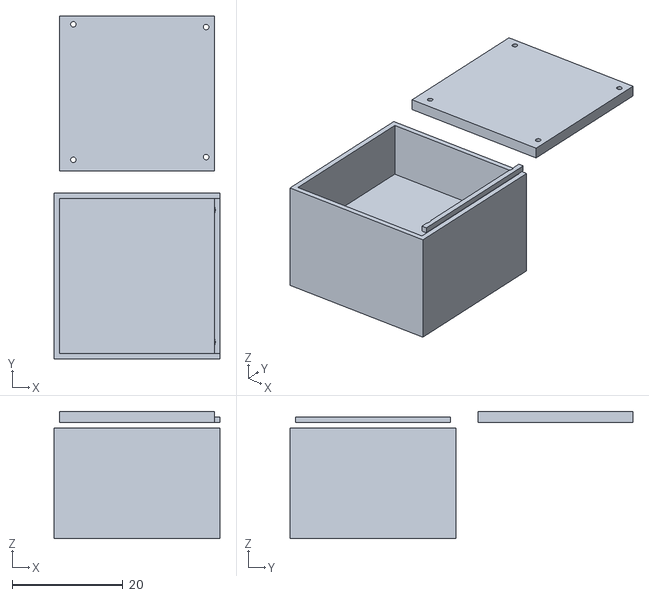
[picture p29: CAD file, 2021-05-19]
COMPONENTES/STL/Caja servomotor.stl
30.0 x 62.0 x 23.0

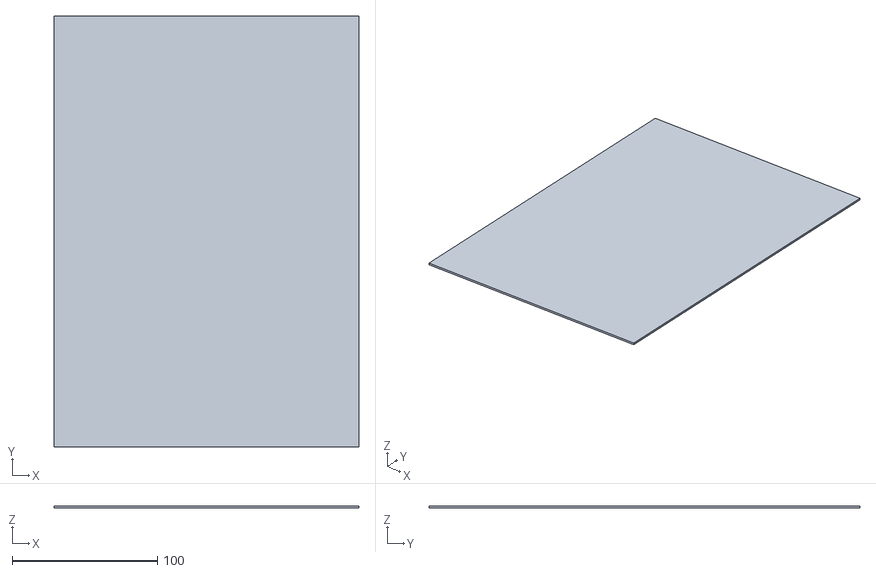
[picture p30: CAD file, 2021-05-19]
COMPONENTES/MTL/Hoja.obj
210.0 x 297.0 x 1.58

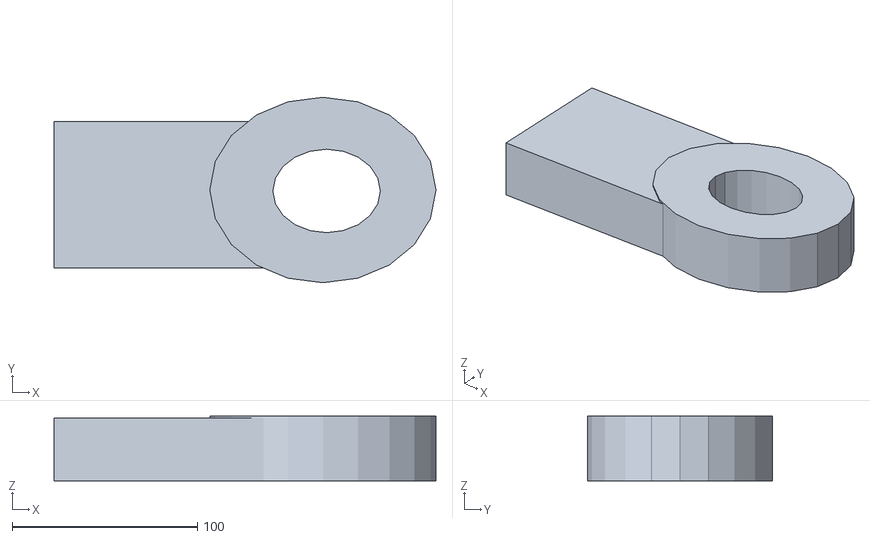
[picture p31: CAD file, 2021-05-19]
COMPONENTES/STL/Soporte_Sensor.stl
206.0 x 100.0 x 35.0

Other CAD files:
COMPONENTES/STL/Zona de vacio.stl
COMPONENTES/MTL/Prismatico.obj
COMPONENTES/MTL/Mesa.obj
COMPONENTES/MTL/Brazo_Rotacional.obj
COMPONENTES/MTL/camara.obj
